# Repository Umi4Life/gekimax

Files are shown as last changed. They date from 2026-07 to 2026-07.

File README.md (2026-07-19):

# gekimax

generic rhythm game keypad controller with a lever

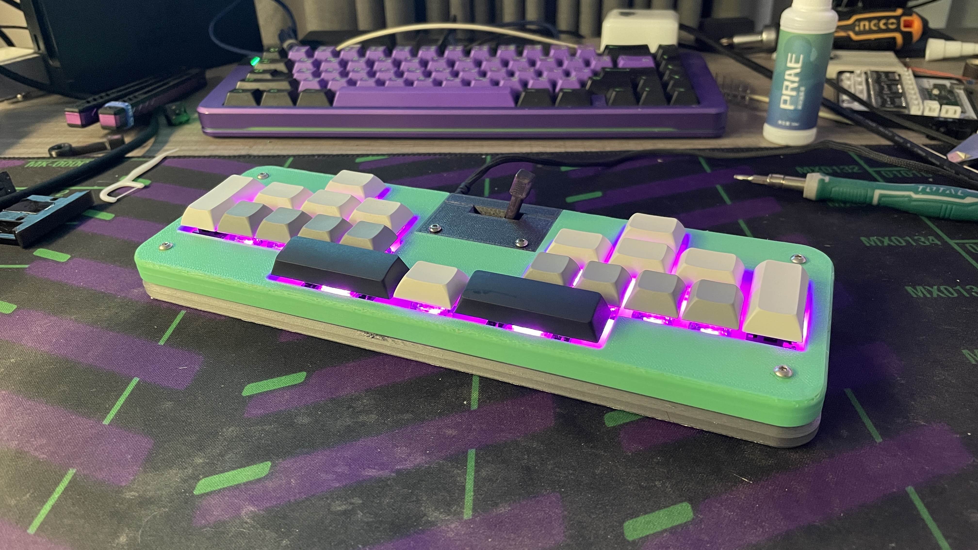
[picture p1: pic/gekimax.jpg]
gekimax

gpio-layout

## BOM (LCSC, also see [the csv](gekimax-pcb/gekimax.csv))

| Part | Amount |
|---|---|
| RK09L11 Rotary Potentiometer | 1 |
| 100nF Capacitor 0805 | 28 |
| SK6812MINI-E LED | 21 |
| USB-C Connector | 5 |
| 220Ω Resistor 0603 | 1 |
| 5.1KΩ Resistor 0603 | 2 |

*RK09 potentiometer may need some disassembly and modding to remove detent*

## BOM (Additional Hardware)

| Part | Amount |
|---|---|
| Raspberry Pi Pico | 1 |
| M3 Heat Insert | 6 |
| M3 Nut | 2 |
| M3x15-16mm Countersunk Screw | 8 |
| M3x40 Button Head Screw | 1 |
| Rubber Feet | 4 |
| Rubber sheet/padding for lever | 1 |
| Keyboard Switches | 21 |
| Hot Swap Socket | 21 |
| Plate Mount Stabilizer | 4 |
| 1U keycaps | 8 |
| 1.25U keycaps | 9 |
| 2U keycaps | 2 |
| 2.75U keycaps | 2 |

## Notes
- Uses [GP2040-CE](https://gp2040-ce.info/) for firmware (need some manual key mapping)
- PCB has some additional side leds that I couldn't get them to work

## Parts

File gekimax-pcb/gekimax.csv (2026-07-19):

Designator | Comment | Footprint | Qty | LCSC
C0,C1,C2,C3,C4,C5,C6,C7,C8,C9,C10,C11,C12,C13,C14,C15,C16,C17,C18,C19,C20,C21,C22,C23,C24,C25,C26,C27 | 100n | Capacitor_SMD:C_0805_2012Metric_Pad1.18x1.45mm_HandSolder | 28 | C48579599
D1,D2,D3,D4,D5,D6,D7,D8,D9,D10,D11,D12,D13,D14,D15,D16,D17,D18,D19,D20,D21 | SK6812MINI | PCM_marbastlib-mx:LED_MX_6028R | 21 | C5149201
D22,D23,D24,D25,D26,D27 | WS2812B-4020 | PCM_marbastlib-xp-various:LED_WS2812_4020 | 6 | C965557
J1 | LEFT_EX | Connector_JST:JST_GH_SM05B-GHS-TB_1x05-1MP_P1.25mm_Horizontal | 1 | C189896
J2 | RIGHT_EX | Connector_JST:JST_GH_SM05B-GHS-TB_1x05-1MP_P1.25mm_Horizontal | 1 | C189896
R1,R2 | 5.1kΩ | Resistor_SMD:R_0603_1608Metric_Pad0.98x0.95mm_HandSolder | 2 | C2907044
R3 | 220Ω | Resistor_SMD:R_0603_1608Metric_Pad0.98x0.95mm_HandSolder | 1 | C107696
RV1 | LEVER | Potentiometer_THT:Potentiometer_Alps_RK09L_Single_Horizontal | 1 | C2830189
SW1 | LEFT_TOP | MX_Hotswap:MX-Hotswap-1.25U | 1
SW2 | LEFT_SIDE | MX_Hotswap:MX-Hotswap-2U | 1
SW3 | LEFT_A | MX_Hotswap:MX-Hotswap-1.25U | 1
SW4 | LEFT_B | MX_Hotswap:MX-Hotswap-1.25U | 1
SW5 | LEFT_C | MX_Hotswap:MX-Hotswap-1.25U | 1
SW6 | LEFT_1 | MX_Hotswap:MX-Hotswap-1U | 1
SW7 | LEFT_2 | MX_Hotswap:MX-Hotswap-1U | 1
SW8 | LEFT_3 | MX_Hotswap:MX-Hotswap-1U | 1
SW9 | LEFT_4 | MX_Hotswap:MX-Hotswap-1U | 1
SW10 | LEFT_SPACE | MX_Hotswap:MX-Hotswap-2U | 1
SW11 | RIGHT_TOP | MX_Hotswap:MX-Hotswap-1.25U | 1
SW12 | RIGHT_SIDE | MX_Hotswap:MX-Hotswap-2U | 1
SW13 | RIGHT_A | MX_Hotswap:MX-Hotswap-1.25U | 1
SW14 | RIGHT_B | MX_Hotswap:MX-Hotswap-1.25U | 1
SW15 | RIGHT_C | MX_Hotswap:MX-Hotswap-1.25U | 1
SW16 | RIGHT_1 | MX_Hotswap:MX-Hotswap-1U | 1
SW17 | RIGHT_2 | MX_Hotswap:MX-Hotswap-1U | 1
SW18 | RIGHT_3 | MX_Hotswap:MX-Hotswap-1U | 1
SW19 | RIGHT_4 | MX_Hotswap:MX-Hotswap-1U | 1
SW20 | RIGHT_SPACE | MX_Hotswap:MX-Hotswap-2U | 1
SW21 | MID_SPACE | MX_Hotswap:MX-Hotswap-2U | 1
U1 | Pico | RPi_Pico:RPi_Pico_SMD | 1
USB1 | HRO-TYPE-C-31-M-12 | Type-C:HRO-TYPE-C-31-M-12-HandSoldering | 1 | C167321

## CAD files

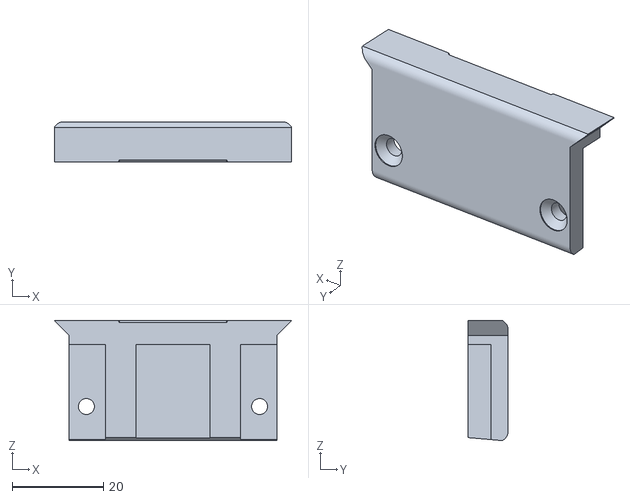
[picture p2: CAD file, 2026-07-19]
gekimax-case/Lever 1.stl
52.0 x 8.87 x 26.4

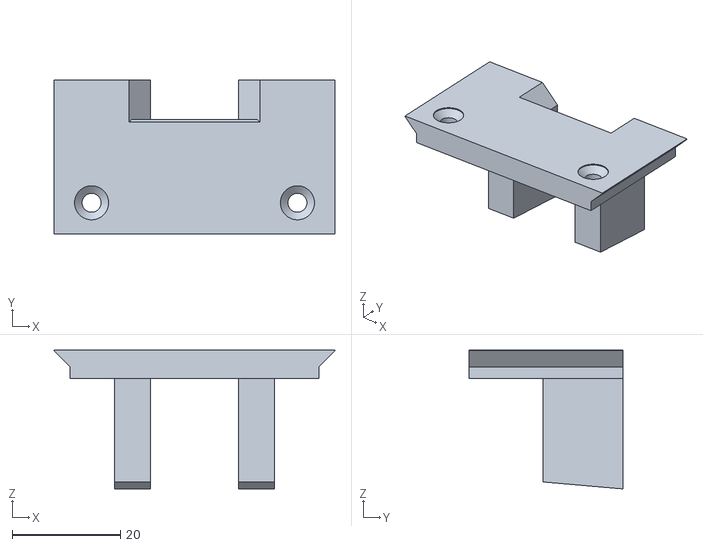
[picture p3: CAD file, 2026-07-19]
gekimax-case/Lever 2.stl
52.0 x 28.5 x 25.7

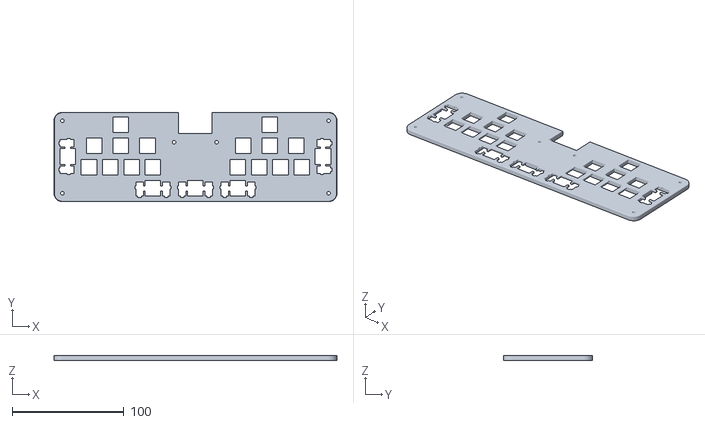
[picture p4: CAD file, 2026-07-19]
gekimax-case/Plate.stl
253.5 x 80.0 x 4.50

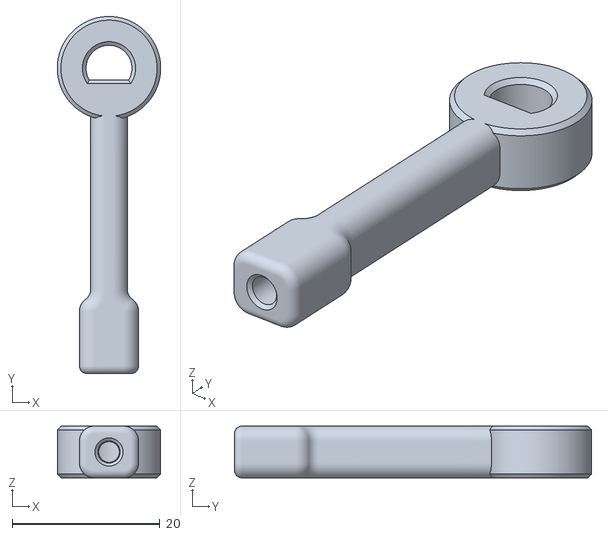
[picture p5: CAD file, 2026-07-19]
gekimax-case/Lever Handle.stl
14.0 x 48.3 x 7.00

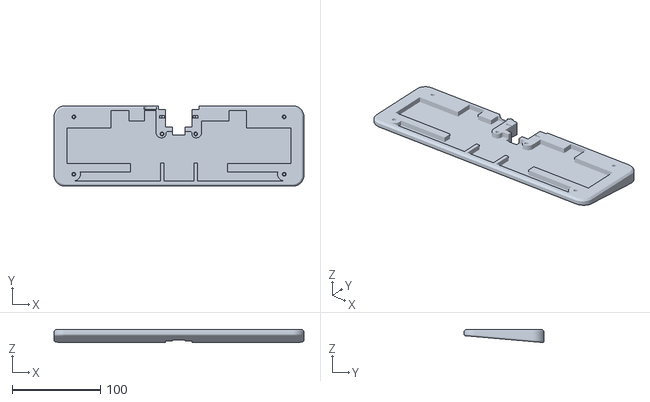
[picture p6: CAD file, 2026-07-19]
gekimax-case/Bottom Case.stl
283.5 x 91.0 x 14.9

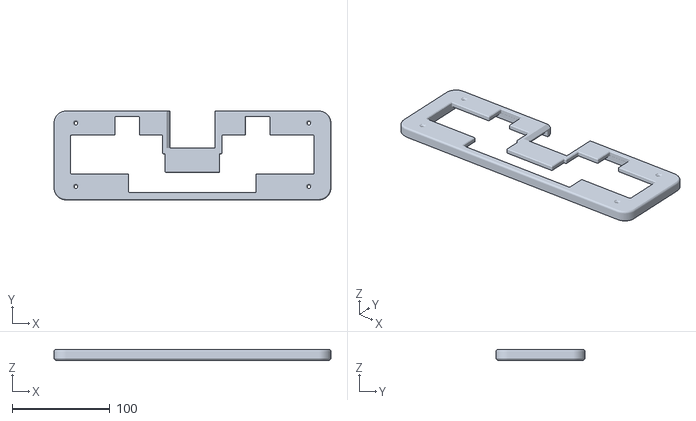
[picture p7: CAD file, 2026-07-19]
gekimax-case/Top case.stl
283.5 x 91.0 x 11.5

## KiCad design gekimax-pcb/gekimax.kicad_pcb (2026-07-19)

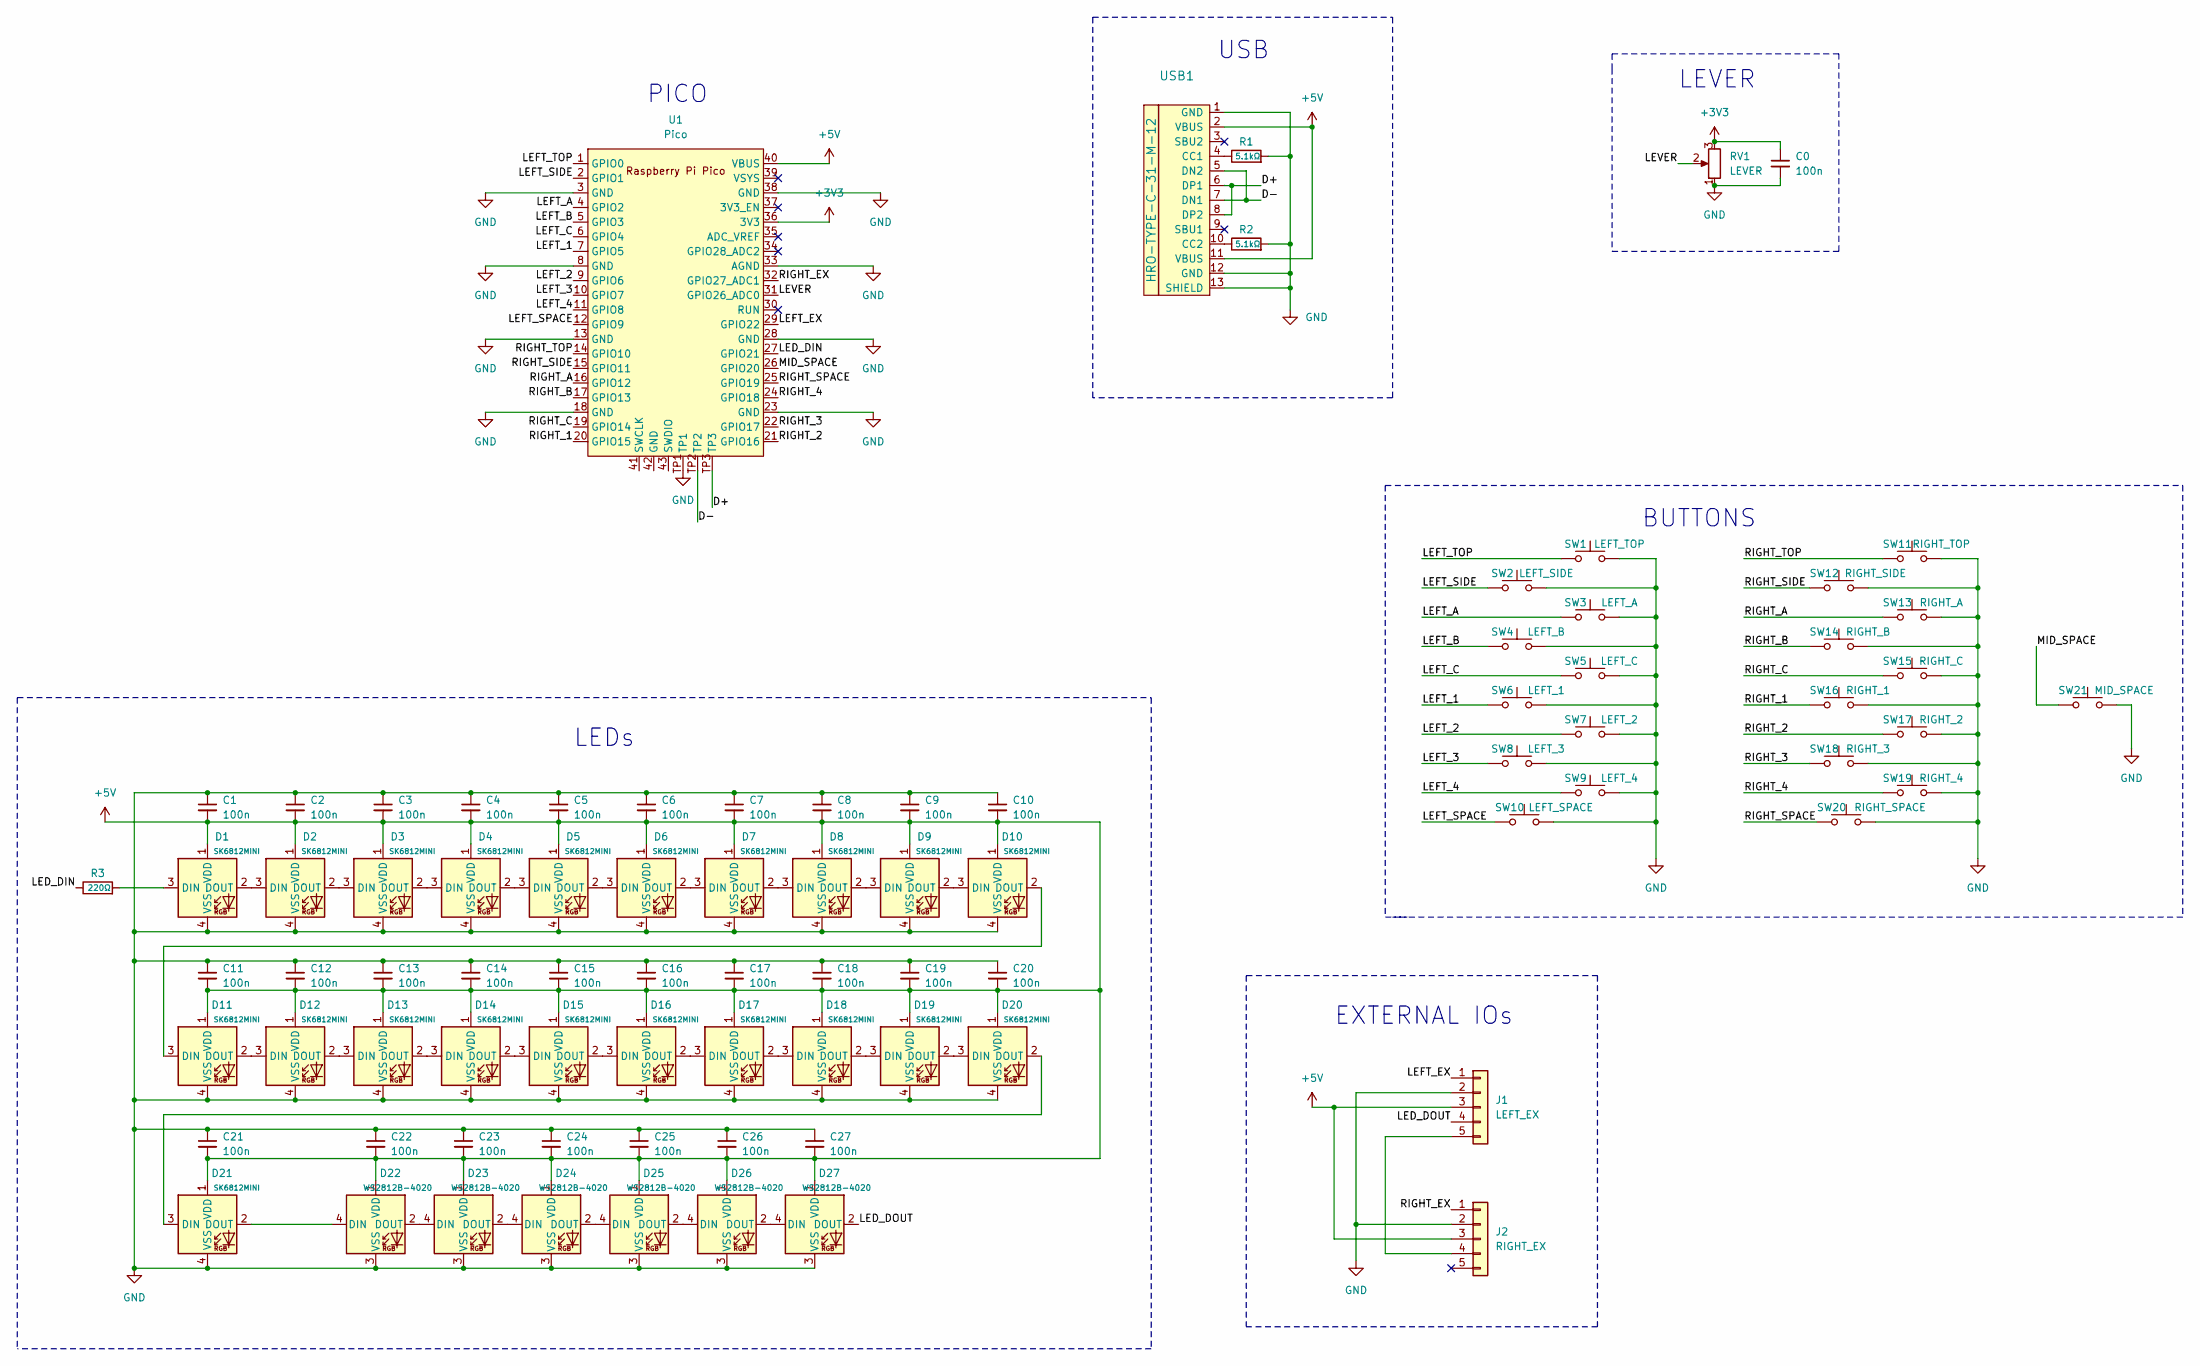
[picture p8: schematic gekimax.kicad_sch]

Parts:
C0, C1, C2, C3, C4, C5, C6, C7, C8, C9, C10, C11, C12, C13, C14, C15, C16, C17, C18, C19, C20, C21, C22, C23, C24, C25, C26, C27: 100n; C_0805_2012Metric_Pad1.18x1.45mm_HandSolder; LCSC C48579599
D1, D2, D3, D4, D5, D6, D7, D8, D9, D10, D11, D12, D13, D14, D15, D16, D17, D18, D19, D20, D21: SK6812MINI; LED_MX_6028R; LCSC C5149201
D22, D23, D24, D25, D26, D27: WS2812B-4020; LED_WS2812_4020; LCSC C965557
J1: LEFT_EX; JST_GH_SM05B-GHS-TB_1x05-1MP_P1.25mm_Horizontal; LCSC C189896
J2: RIGHT_EX; JST_GH_SM05B-GHS-TB_1x05-1MP_P1.25mm_Horizontal; LCSC C189896
R1, R2: 5.1kΩ; R_0603_1608Metric_Pad0.98x0.95mm_HandSolder; LCSC C2907044
R3: 220Ω; R_0603_1608Metric_Pad0.98x0.95mm_HandSolder; LCSC C107696
RV1: LEVER; Potentiometer_Alps_RK09L_Single_Horizontal; LCSC C2830189
SW1: LEFT_TOP; MX-Hotswap-1.25U
SW2: LEFT_SIDE; MX-Hotswap-2U
SW3: LEFT_A; MX-Hotswap-1.25U
SW4: LEFT_B; MX-Hotswap-1.25U
SW5: LEFT_C; MX-Hotswap-1.25U
SW6: LEFT_1; MX-Hotswap-1U
SW7: LEFT_2; MX-Hotswap-1U
SW8: LEFT_3; MX-Hotswap-1U
SW9: LEFT_4; MX-Hotswap-1U
SW10: LEFT_SPACE; MX-Hotswap-2U
SW11: RIGHT_TOP; MX-Hotswap-1.25U
SW12: RIGHT_SIDE; MX-Hotswap-2U
SW13: RIGHT_A; MX-Hotswap-1.25U
SW14: RIGHT_B; MX-Hotswap-1.25U
SW15: RIGHT_C; MX-Hotswap-1.25U
SW16: RIGHT_1; MX-Hotswap-1U
SW17: RIGHT_2; MX-Hotswap-1U
SW18: RIGHT_3; MX-Hotswap-1U
SW19: RIGHT_4; MX-Hotswap-1U
SW20: RIGHT_SPACE; MX-Hotswap-2U
SW21: MID_SPACE; MX-Hotswap-2U
U1: Pico; RPi_Pico_SMD
USB1: HRO-TYPE-C-31-M-12; HRO-TYPE-C-31-M-12-HandSoldering; LCSC C167321

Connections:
+3V3: C0.1, RV1.3, U1.36 (3V3)
+5V: C1.2, C2.2, C3.2, C4.2, C5.2, C6.2, C7.2, C8.2, C9.2, C10.2, C11.2, C12.2, C13.2, C14.2, C15.2, C16.2, C17.2, C18.2, C19.2, C20.2, C21.2, C22.2, C23.2, C24.2, C25.2, C26.2, C27.2, D1.1 (VDD), D2.1 (VDD), D3.1 (VDD), D4.1 (VDD), D5.1 (VDD), D6.1 (VDD), D7.1 (VDD), D8.1 (VDD), D9.1 (VDD), D10.1 (VDD), D11.1 (VDD), D12.1 (VDD), D13.1 (VDD), D14.1 (VDD), D15.1 (VDD), D16.1 (VDD), D17.1 (VDD), D18.1 (VDD), D19.1 (VDD), D20.1 (VDD), D21.1 (VDD), D22.1 (VDD), D23.1 (VDD), D24.1 (VDD), D25.1 (VDD), D26.1 (VDD), D27.1 (VDD), J1.3, J2.3, U1.40 (VBUS), USB1.2 (VBUS), USB1.11 (VBUS)
/D+: U1.TP3, USB1.6 (DP1), USB1.8 (DP2)
/D-: U1.TP2, USB1.5 (DN2), USB1.7 (DN1)
/LED_DIN: R3.1, U1.27 (GPIO21)
/LED_DOUT: D27.2 (DOUT), J1.4
/LEFT_1: SW6.1, U1.7 (GPIO5)
/LEFT_2: SW7.1, U1.9 (GPIO6)
/LEFT_3: SW8.1, U1.10 (GPIO7)
/LEFT_4: SW9.1, U1.11 (GPIO8)
/LEFT_A: SW3.1, U1.4 (GPIO2)
/LEFT_B: SW4.1, U1.5 (GPIO3)
/LEFT_C: SW5.1, U1.6 (GPIO4)
/LEFT_EX: J1.1, U1.29 (GPIO22)
/LEFT_SIDE: SW2.1, U1.2 (GPIO1)
/LEFT_SPACE: SW10.1, U1.12 (GPIO9)
/LEFT_TOP: SW1.1, U1.1 (GPIO0)
/LEVER: RV1.2, U1.31 (GPIO26_ADC0)
/MID_SPACE: SW21.1, U1.26 (GPIO20)
/RIGHT_1: SW16.1, U1.20 (GPIO15)
/RIGHT_2: SW17.1, U1.21 (GPIO16)
/RIGHT_3: SW18.1, U1.22 (GPIO17)
/RIGHT_4: SW19.1, U1.24 (GPIO18)
/RIGHT_A: SW13.1, U1.16 (GPIO12)
/RIGHT_B: SW14.1, U1.17 (GPIO13)
/RIGHT_C: SW15.1, U1.19 (GPIO14)
/RIGHT_EX: J2.1, U1.32 (GPIO27_ADC1)
/RIGHT_SIDE: SW12.1, U1.15 (GPIO11)
/RIGHT_SPACE: SW20.1, U1.25 (GPIO19)
/RIGHT_TOP: SW11.1, U1.14 (GPIO10)
GND: C0.2, C1.1, C2.1, C3.1, C4.1, C5.1, C6.1, C7.1, C8.1, C9.1, C10.1, C11.1, C12.1, C13.1, C14.1, C15.1, C16.1, C17.1, C18.1, C19.1, C20.1, C21.1, C22.1, C23.1, C24.1, C25.1, C26.1, C27.1, D1.4 (VSS), D2.4 (VSS), D3.4 (VSS), D4.4 (VSS), D5.4 (VSS), D6.4 (VSS), D7.4 (VSS), D8.4 (VSS), D9.4 (VSS), D10.4 (VSS), D11.4 (VSS), D12.4 (VSS), D13.4 (VSS), D14.4 (VSS), D15.4 (VSS), D16.4 (VSS), D17.4 (VSS), D18.4 (VSS), D19.4 (VSS), D20.4 (VSS), D21.4 (VSS), D22.3 (VSS), D23.3 (VSS), D24.3 (VSS), D25.3 (VSS), D26.3 (VSS), D27.3 (VSS), J1.2, J2.2, R1.2, R2.2, RV1.1, SW1.2, SW2.2, SW3.2, SW4.2, SW5.2, SW6.2, SW7.2, SW8.2, SW9.2, SW10.2, SW11.2, SW12.2, SW13.2, SW14.2, SW15.2, SW16.2, SW17.2, SW18.2, SW19.2, SW20.2, SW21.2, U1.3 (GND), U1.8 (GND), U1.13 (GND), U1.18 (GND), U1.23 (GND), U1.28 (GND), U1.33 (AGND), U1.38 (GND), U1.TP1, USB1.1 (GND), USB1.12 (GND), USB1.13 (SHIELD)
unnamed: D1.3 (DIN), R3.2
unnamed: D1.2 (DOUT), D2.3 (DIN)
unnamed: D2.2 (DOUT), D3.3 (DIN)
unnamed: D3.2 (DOUT), D4.3 (DIN)
unnamed: D4.2 (DOUT), D5.3 (DIN)
unnamed: D5.2 (DOUT), D6.3 (DIN)
unnamed: D6.2 (DOUT), D7.3 (DIN)
unnamed: D7.2 (DOUT), D8.3 (DIN)
unnamed: D8.2 (DOUT), D9.3 (DIN)
unnamed: D9.2 (DOUT), D10.3 (DIN)
unnamed: D10.2 (DOUT), D11.3 (DIN)
unnamed: D11.2 (DOUT), D12.3 (DIN)
unnamed: D12.2 (DOUT), D13.3 (DIN)
unnamed: D13.2 (DOUT), D14.3 (DIN)
unnamed: D14.2 (DOUT), D15.3 (DIN)
unnamed: D15.2 (DOUT), D16.3 (DIN)
unnamed: D16.2 (DOUT), D17.3 (DIN)
unnamed: D17.2 (DOUT), D18.3 (DIN)
unnamed: D18.2 (DOUT), D19.3 (DIN)
unnamed: D19.2 (DOUT), D20.3 (DIN)
unnamed: D20.2 (DOUT), D21.3 (DIN)
unnamed: D21.2 (DOUT), D22.4 (DIN)
unnamed: D22.2 (DOUT), D23.4 (DIN)
unnamed: D23.2 (DOUT), D24.4 (DIN)
unnamed: D24.2 (DOUT), D25.4 (DIN)
unnamed: D25.2 (DOUT), D26.4 (DIN)
unnamed: D26.2 (DOUT), D27.4 (DIN)
unnamed: J1.5, J2.4
unnamed: R1.1, USB1.4 (CC1)
unnamed: R2.1, USB1.10 (CC2)

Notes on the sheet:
USB
PICO
BUTTONS
LEDs
EXTERNAL IOs
LEVER

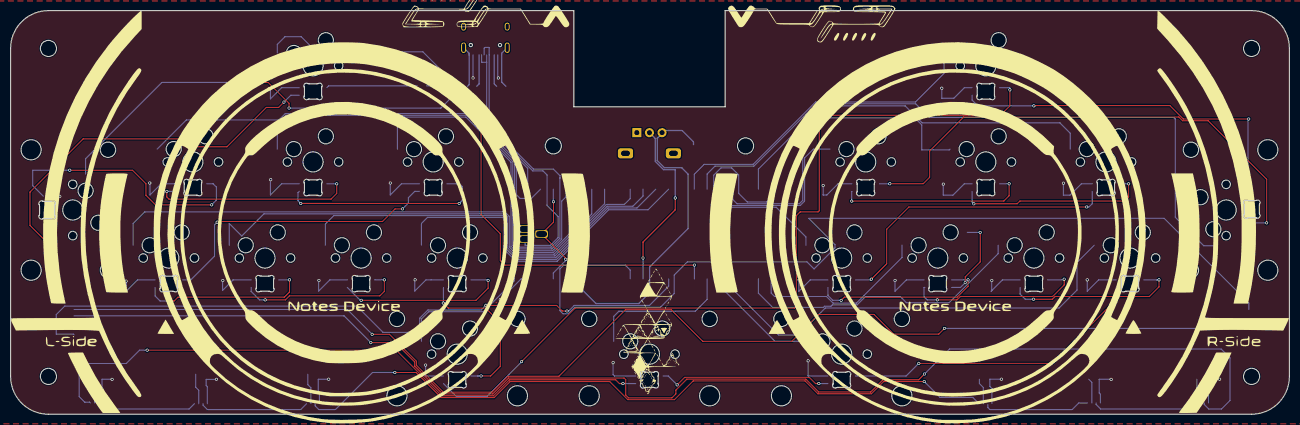
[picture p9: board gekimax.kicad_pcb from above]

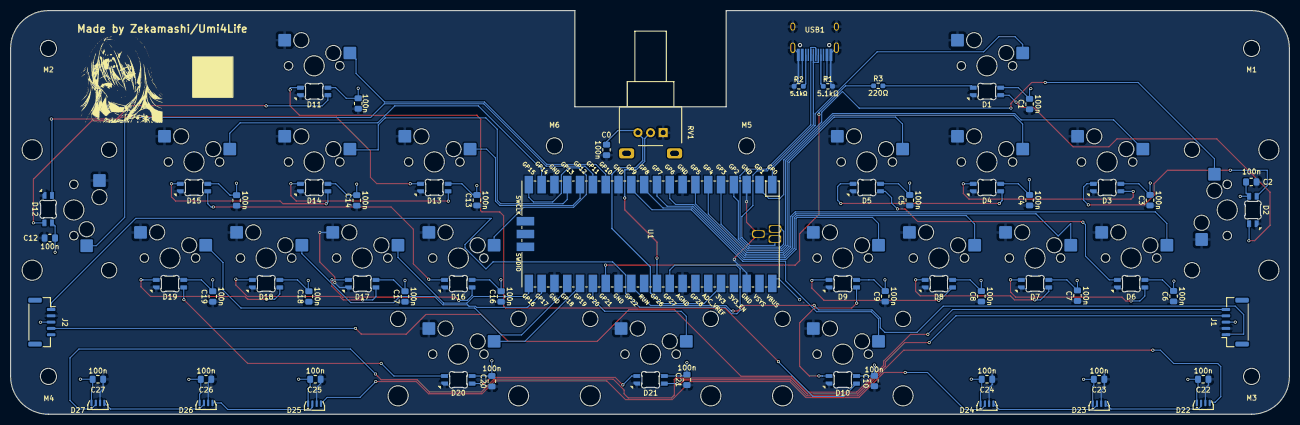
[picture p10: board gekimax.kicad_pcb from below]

Board: 2 copper layers, 253.5 x 80.0 mm, 90 parts (69 on the bottom side), 61 nets.

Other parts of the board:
M1, M2, M3, M4, M5, M6: MountingHole_3.2mm_M3
